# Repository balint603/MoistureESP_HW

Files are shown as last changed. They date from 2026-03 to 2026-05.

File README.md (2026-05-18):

# Hardware for MoistureESP project.
## Description
This project aims to use the ESP32 in low power modes, discover its capabilites for low power application. Also, this sensor project would be useful for home gardens not to forget watering.
This is not a complete product, it can be considered as a devboard.

*Software component not published yet.*
*3D case not published yet.*
## Software
See repository: [https://github.com/balint603/moist](https://github.com/balint603/moist)
## Components
- *This PCB project*
- ESP32-WROOM-32
- SOILCAP-V20 humidity measure
- DS18B20 sensor
- *SW not ready yet*
- *BMS configuration not ready yet*
## Features
- BMS cell protection.
- Overvoltage protection for battery input.
- Charger with USB (not tested).
- Wi-Fi MQTT data transmission.
- Selectable sensor measure interval.
## Interfaces
- Wi-Fi communication aimed to be used for sharing sensor data.
- Analog input for moisture sensor board (SOILCAP-V20).
- 1-Wire interface for DS18B20 temperature sensor.
- BMS I2C lines.
- UART for ESP programming and debug with RTS, DTS secondary programming feature.
- *Optional I2C for display.*
## Power
- Sized for 18650 battery cell, BMS tested with NCR18650B.
- Optinally Li-ion charger can be connected.
- Built-in USB charger was not tested.
### BMS configuration
1. Disable 2 cell: Settings->DA configuration->CC0 bit needs to be set to zero.
    - Otherwise it causes CUV and discharge FET will not turn on.
## Prerequisites
- KiCAD v10.0.0 

## Release
- V1.0: USB charger not tested.

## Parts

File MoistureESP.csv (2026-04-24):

Reference | Qty | Value | DNP | Exclude from BOM | Exclude from Board | Footprint | Datasheet | Tolerance
Batt1 | 1 | NCR18650B |  |  |  | custom:NCR18650
C1,C2,C3,C4,C6,C7,C8,C9,C14,C15,C16,C27 | 12 | 100nF |  |  |  | Capacitor_SMD:C_0603_1608Metric_Pad1.08x0.95mm_HandSolder
C5,C12,C13 | 3 | 2.2uF |  |  |  | Capacitor_SMD:C_0603_1608Metric_Pad1.08x0.95mm_HandSolder
C10,C11 | 2 | 1uF |  |  |  | Capacitor_SMD:C_0603_1608Metric_Pad1.08x0.95mm_HandSolder
C17 | 1 | 22uF |  |  |  | Capacitor_SMD:C_0603_1608Metric_Pad1.08x0.95mm_HandSolder
C18,C20,C21 | 3 | 2.2uF | DNP |  |  | Capacitor_SMD:C_0603_1608Metric_Pad1.08x0.95mm_HandSolder
C19 | 1 | 100nF | DNP |  |  | Capacitor_SMD:C_0603_1608Metric_Pad1.08x0.95mm_HandSolder
C22,C23,C24,C25 | 4 | 10uF | DNP |  |  | Capacitor_SMD:C_0603_1608Metric_Pad1.08x0.95mm_HandSolder
C26 | 1 | 22uF | DNP |  |  | Capacitor_SMD:C_0603_1608Metric_Pad1.08x0.95mm_HandSolder
D1,D2 | 2 | ESD5Zxx |  |  |  | Diode_SMD:D_SOD-523 | https://www.onsemi.com/pdf/datasheet/esd5z2.5t1-d.pdf
D3 | 1 | BZT52H-AD3V3-QX | DNP |  |  | Diode_SMD:D_SOD-123F | https://diotec.com/tl_files/diotec/files/pdf/datasheets/bzt52b2v4.pdf
D4,D5 | 2 | LED | DNP |  |  | LED_SMD:LED_0603_1608Metric
D6,D7 | 2 | BZT52H-AD3V3-QX |  |  |  | Diode_SMD:D_SOD-123F | https://diotec.com/tl_files/diotec/files/pdf/datasheets/bzt52b2v4.pdf
D8 | 1 | BZT52H-B5V1 |  |  |  | Diode_SMD:D_SOD-123F | https://diotec.com/tl_files/diotec/files/pdf/datasheets/bzt52b2v4.pdf
F1 | 1 | 2.5A |  |  |  | Resistor_SMD:R_0603_1608Metric_Pad0.98x0.95mm_HandSolder
F2 | 1 | 500mA |  |  |  | Resistor_SMD:R_1206_3216Metric_Pad1.30x1.75mm_HandSolder
J1 | 1 | Conn_01x02_Pin |  |  |  | Connector_PinHeader_2.54mm:PinHeader_1x02_P2.54mm_Vertical
J2 | 1 | Conn_MoisturePCB |  |  |  | custom:sensorwirepads3x1
J3 | 1 | Conn_DS18B20 |  |  |  | custom:sensorwirepads3x1
J4 | 1 | Conn_01x06_Pin |  |  |  | Connector_PinHeader_2.54mm:PinHeader_1x06_P2.54mm_Vertical
J5 | 1 | Conn_01x03_Pin |  |  |  | Connector_PinHeader_2.54mm:PinHeader_1x03_P2.54mm_Vertical
J6 | 1 | Conn_01x04_Pin | DNP |  |  | Connector_PinHeader_2.54mm:PinHeader_1x04_P2.54mm_Vertical
J7 | 1 | USB4110-GF-A | DNP |  |  | custom:USB4110-GF-A_GCT | USB4110-GF-A
JP1,JP2 | 2 | Jumper_2_Bridged |  |  |  | Connector_PinHeader_2.54mm:PinHeader_1x02_P2.54mm_Vertical
L1 | 1 | HTEK25201T-R47MSR | DNP |  |  | Inductor_SMD:L_1008_2520Metric_Pad1.43x2.20mm_HandSolder
Q1,Q2 | 2 | SSM6K513NU-LF |  |  |  | custom:TRANS_SSM6K513NU-LF
Q3 | 1 | 2N7002W |  |  |  | custom:SOT65P220X100-3N
Q4,Q5 | 2 | RUM002N05T2L |  |  |  | Package_TO_SOT_SMD:SOT-723
Q6,Q7 | 2 | BC817W |  |  |  | Package_TO_SOT_SMD:SOT-323_SC-70 | https://www.onsemi.com/pub/Collateral/BC818-D.pdf
Q8,Q10 | 2 | SI7137DP-T1-GE3 |  |  |  | custom:MOSFET_7DP-T1-GE3_VIS | https://www.vishay.com/doc?69063
Q9 | 1 | BC856BLT1G0SCT-ND |  |  |  | Package_TO_SOT_SMD:SOT-23 | https://www.onsemi.com/pub/Collateral/BC860-D.pdf
R1,R3,R4,R10,R11,R13,R25 | 7 | 100R |  |  |  | Resistor_SMD:R_0603_1608Metric_Pad0.98x0.95mm_HandSolder
R2 | 1 | 2mR |  |  |  | Resistor_SMD:R_1206_3216Metric_Pad1.30x1.75mm_HandSolder |  | 1%
R5,R8 | 2 | 10M |  |  |  | Resistor_SMD:R_0603_1608Metric_Pad0.98x0.95mm_HandSolder
R6,R7 | 2 | 5K1 |  |  |  | Resistor_SMD:R_0603_1608Metric_Pad0.98x0.95mm_HandSolder
R9,R14,R15,R16,R23,R24,R26,R27,R28,R29,R30,R31,R39,R40,R41,R42,R43 | 17 | 10K |  |  |  | Resistor_SMD:R_0603_1608Metric_Pad0.98x0.95mm_HandSolder
R12 | 1 | 5R1 |  |  |  | Resistor_SMD:R_0603_1608Metric_Pad0.98x0.95mm_HandSolder
R17,R19 | 2 | 1.5M |  |  |  | Resistor_SMD:R_0603_1608Metric_Pad0.98x0.95mm_HandSolder |  | 1%
R18,R20 | 2 | 1.2M |  |  |  | Resistor_SMD:R_0603_1608Metric_Pad0.98x0.95mm_HandSolder |  | 1%
R21 | 1 | 5.1K | DNP |  |  | Resistor_SMD:R_0603_1608Metric_Pad0.98x0.95mm_HandSolder
R22 | 1 | 8.1K | DNP |  |  | Resistor_SMD:R_0603_1608Metric_Pad0.98x0.95mm_HandSolder
R32,R33 | 2 | 470R | DNP |  |  | Resistor_SMD:R_0603_1608Metric_Pad0.98x0.95mm_HandSolder
R34 | 1 | 10K | DNP |  |  | Resistor_SMD:R_0603_1608Metric_Pad0.98x0.95mm_HandSolder
R35 | 1 | 11K | DNP |  |  | Resistor_SMD:R_0603_1608Metric_Pad0.98x0.95mm_HandSolder
R36 | 1 | 4.7K |  |  |  | Resistor_SMD:R_0603_1608Metric_Pad0.98x0.95mm_HandSolder
R37 | 1 | 0R |  |  |  | Resistor_SMD:R_0603_1608Metric_Pad0.98x0.95mm_HandSolder
R38 | 1 | 15K |  |  |  | Resistor_SMD:R_0603_1608Metric_Pad0.98x0.95mm_HandSolder
SW1 | 1 | 147873-1 |  |  |  | custom:SW_147873-1
TH1 | 1 | NTCG103JH103JT1 |  |  |  | Resistor_SMD:R_0402_1005Metric_Pad0.72x0.64mm_HandSolder
U1 | 1 | BQ28Z620DRZR |  |  |  | custom:VSON12_DRZ_TEX-L
U2,U3 | 2 | TPS7A2601DRVR |  |  |  | custom:DRV0006A
U4 | 1 | ESP32-WROOM-32 |  |  |  | RF_Module:ESP32-WROOM-32 | https://www.espressif.com/sites/default/files/documentation/esp32-wroom-32_datasheet_en.pdf
U5 | 1 | MAX77757JEFG420+ | DNP |  |  | 21-100385B_90-100128_MXM | MAX77757HEFG360+

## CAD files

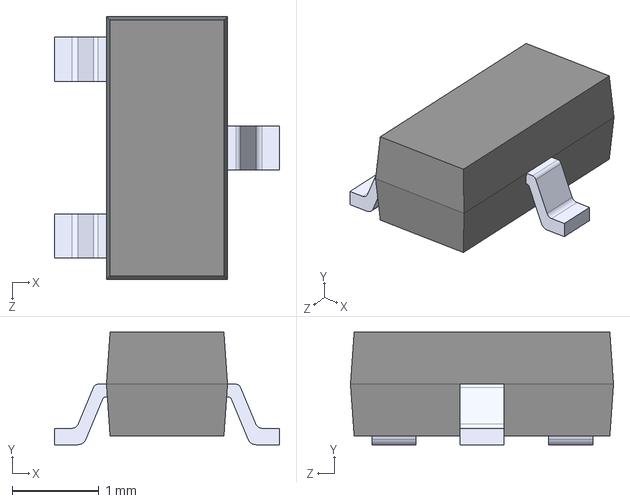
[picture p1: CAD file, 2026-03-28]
footprints/2N7002W/2N7002W.step
2.60 x 1.30 x 3.04 mm

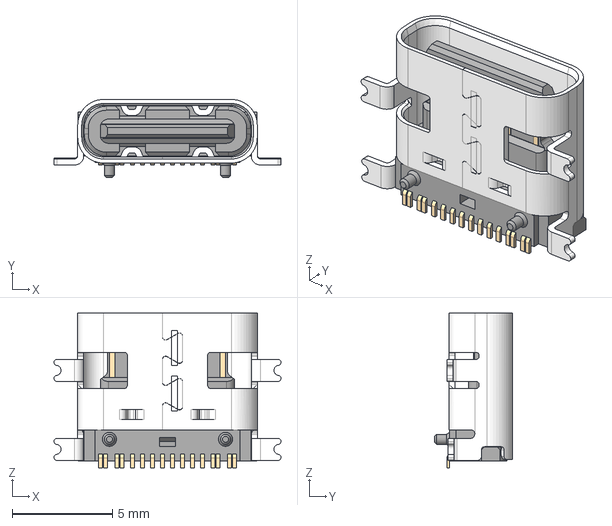
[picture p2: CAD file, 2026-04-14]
footprints/USB4110-GF-A.stp
11.3 x 3.89 x 7.70 mm

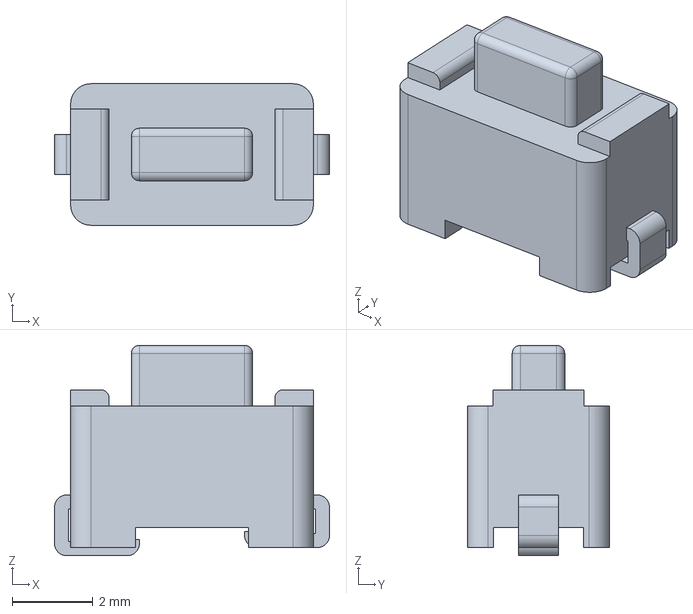
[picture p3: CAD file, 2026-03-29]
footprints/147873-1/147873-1.step
6.80 x 3.50 x 5.20 mm

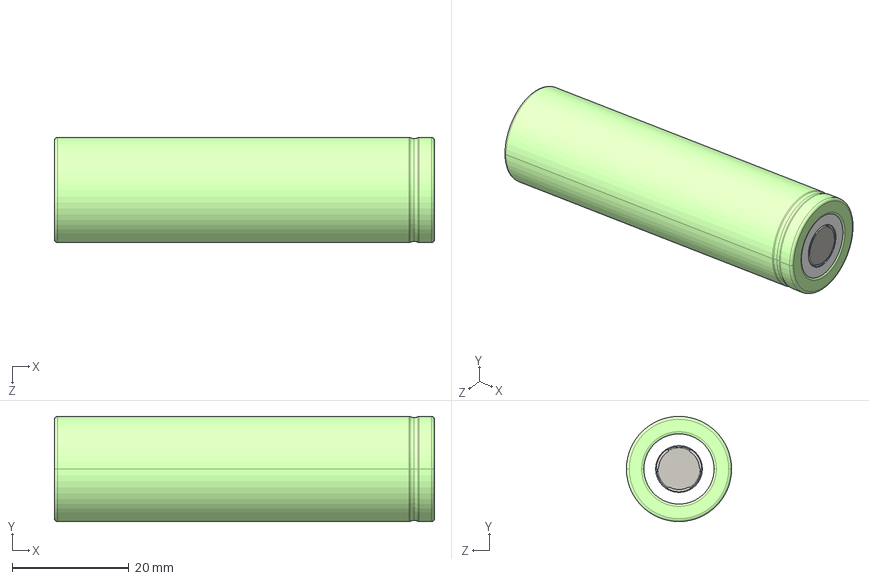
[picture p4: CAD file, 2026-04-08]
footprints/18650 battery.STEP
65.0 x 18.0 x 18.0 mm
battery terminal -
battery washer
battery case
battery terminal +

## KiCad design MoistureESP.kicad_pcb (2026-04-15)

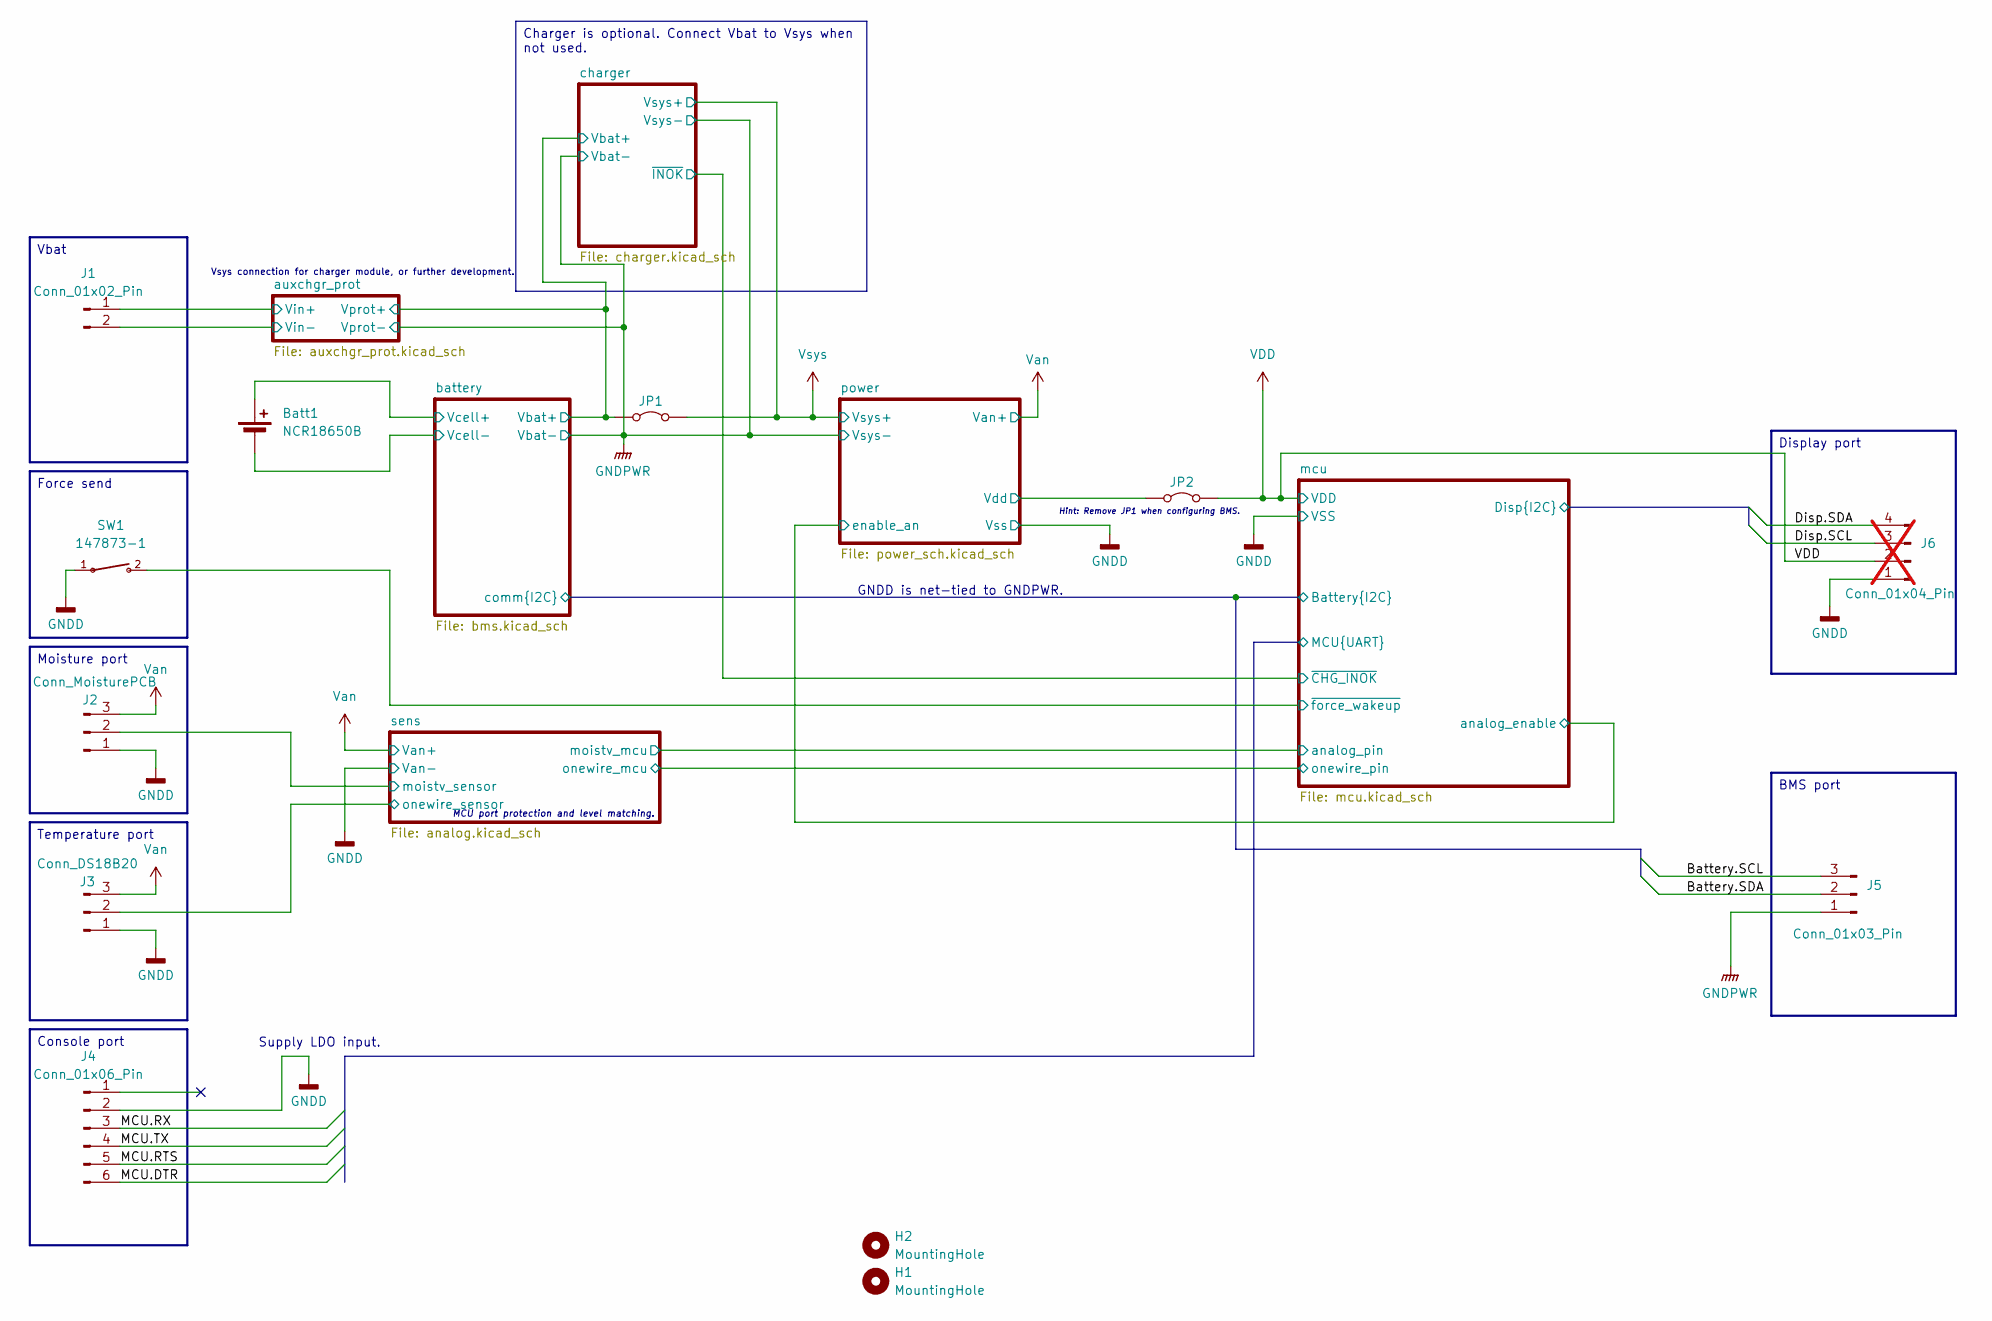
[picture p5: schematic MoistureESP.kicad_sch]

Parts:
Batt1: NCR18650B; NCR18650
H1, H2: MountingHole; MountingHole_2.7mm_M2.5_DIN965
J1: Conn_01x02_Pin; PinHeader_1x02_P2.54mm_Vertical
J2: Conn_MoisturePCB; sensorwirepads3x1
J3: Conn_DS18B20; sensorwirepads3x1
J4: Conn_01x06_Pin; PinHeader_1x06_P2.54mm_Vertical
J5: Conn_01x03_Pin; PinHeader_1x03_P2.54mm_Vertical
J6: Conn_01x04_Pin; PinHeader_1x04_P2.54mm_Vertical; not fitted
JP1, JP2: Jumper_2_Bridged; PinHeader_1x02_P2.54mm_Vertical
SW1: 147873-1; SW_147873-1; PARTREV K3

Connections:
/auxchgr_prot/Vin+: J1.1; also elsewhere on the board
/battery/Vcell+: Batt1.1 (+); also elsewhere on the board
/battery/comm.SCL: J5.3; also elsewhere on the board
/battery/comm.SDA: J5.2; also elsewhere on the board
/charger/VBat: JP1.1 (A); also elsewhere on the board
/mcu/Disp.SCL: J6.3; also elsewhere on the board
/mcu/Disp.SDA: J6.4; also elsewhere on the board
/mcu/MCU.DTR: J4.6; also elsewhere on the board
/mcu/MCU.RTS: J4.5; also elsewhere on the board
/mcu/MCU.RX: J4.3; also elsewhere on the board
/mcu/MCU.TX: J4.4; also elsewhere on the board
/mcu/onewire_pin: J3.2; also elsewhere on the board
/mcu/~force_wakeup: SW1.2; also elsewhere on the board
/power/Vdd: JP2.1 (A); also elsewhere on the board
/sens/moistv_sensor: J2.2; also elsewhere on the board
CGND: Batt1.2 (-); also elsewhere on the board
GNDD: J2.1, J3.1, J4.2, J6.1, SW1.1; also elsewhere on the board
GNDPWR: J1.2, J5.1; also elsewhere on the board
VDD: J6.2, JP2.2 (B); also elsewhere on the board
Van: J2.3, J3.3; also elsewhere on the board
Vsys: JP1.2 (B); also elsewhere on the board

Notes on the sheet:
Vsys connection for charger module, or further development.
MCU port protection and level matching.
Supply LDO input.
GNDD is net-tied to GNDPWR.
Hint: Remove JP1 when configuring BMS.
Vbat
Temperature port
Force send
Console port
Charger is optional. Connect Vbat to Vsys when not used.
Display port
BMS port
Moisture port

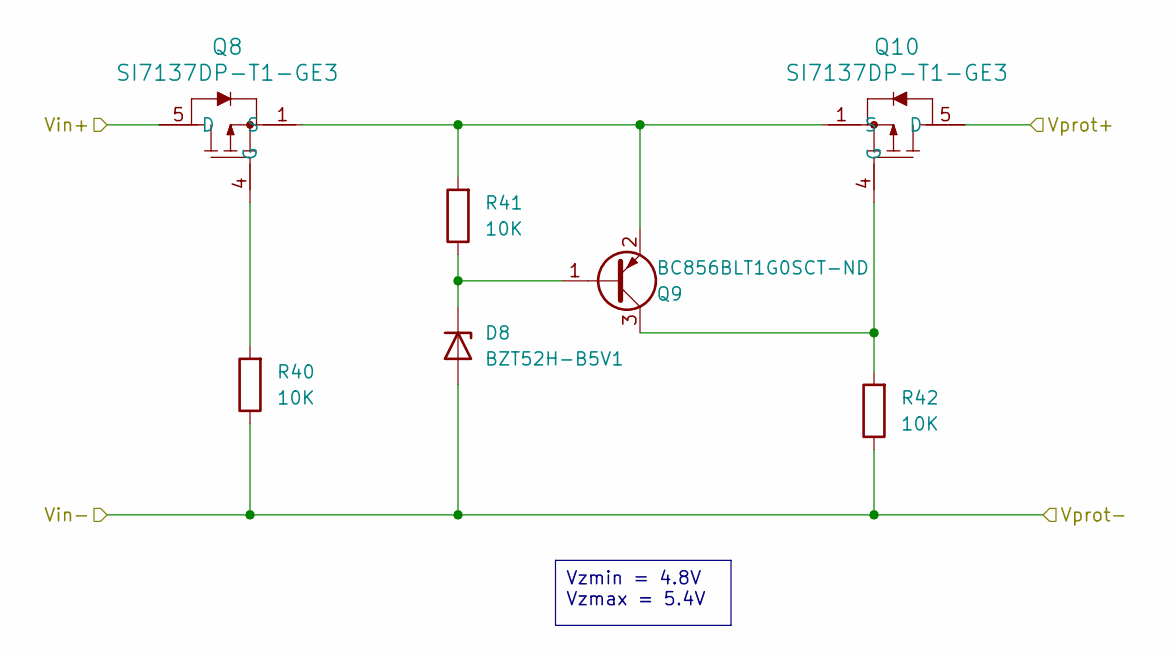
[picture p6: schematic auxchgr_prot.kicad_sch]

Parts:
D8: BZT52H-B5V1; D_SOD-123F
Q8, Q10: SI7137DP-T1-GE3; MOSFET_7DP-T1-GE3_VIS
Q9: BC856BLT1G0SCT-ND; SOT-23
R40, R41, R42: 10K; R_0603_1608Metric_Pad0.98x0.95mm_HandSolder

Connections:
/auxchgr_prot/Vin+: Q8.5 (D); also elsewhere on the board
/charger/VBat: Q10.5 (D); also elsewhere on the board
GNDPWR: D8.2 (A), R40.1, R42.1; also elsewhere on the board
unnamed: D8.1 (K), Q9.1 (B), R41.1
unnamed: Q8.4 (G), R40.2
unnamed: Q8.1 (S), Q8.2 (S), Q8.3 (S), Q9.2 (E), Q10.1 (S), Q10.2 (S), Q10.3 (S), R41.2
unnamed: Q9.3 (C), Q10.4 (G), R42.2

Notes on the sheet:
Vzmin = 4.8V Vzmax = 5.4V

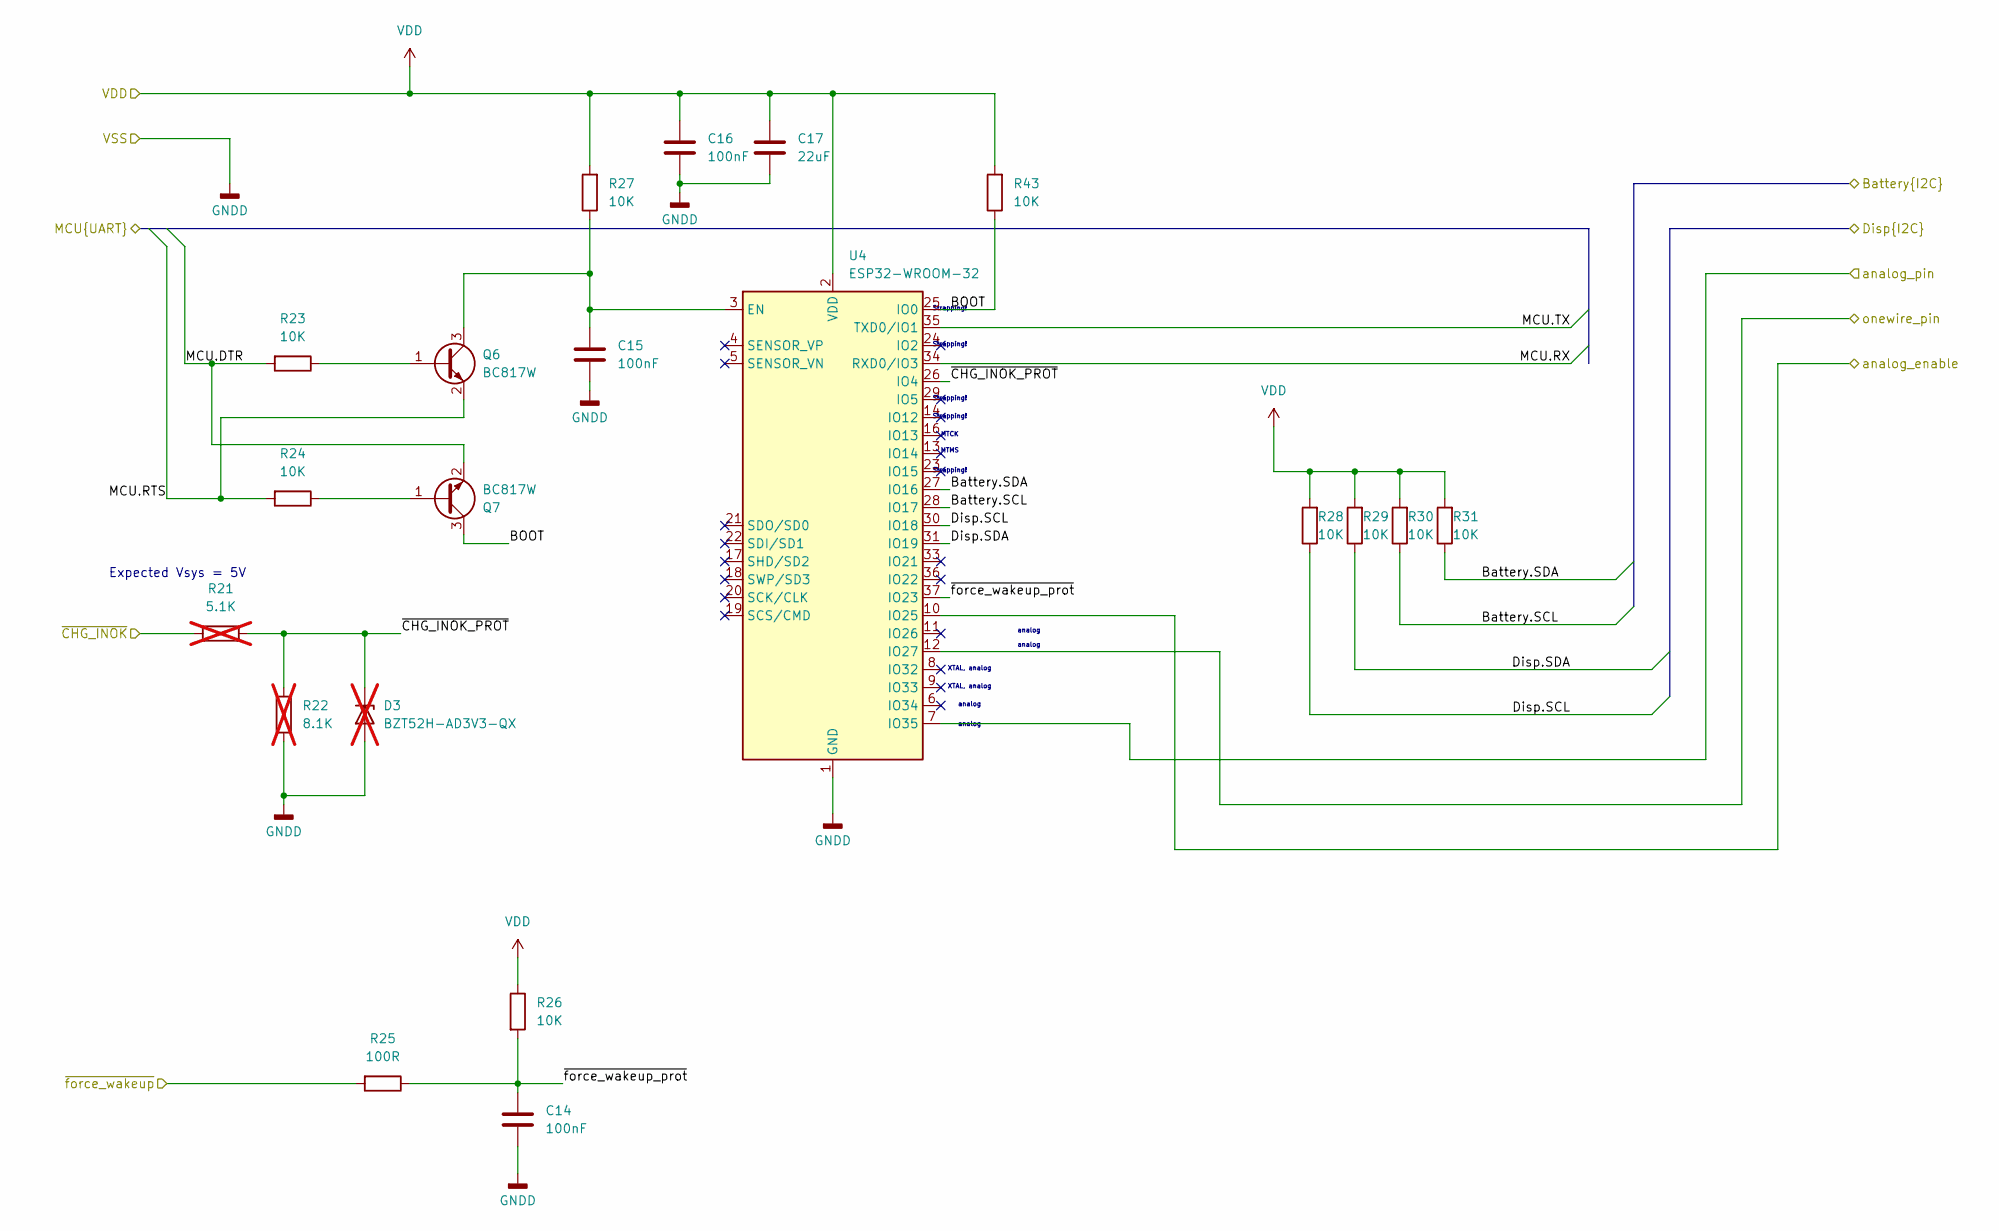
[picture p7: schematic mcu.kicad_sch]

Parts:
C14, C15, C16: 100nF; C_0603_1608Metric_Pad1.08x0.95mm_HandSolder; Voltage 25V
C17: 22uF; C_0603_1608Metric_Pad1.08x0.95mm_HandSolder; Voltage 10V
D3: BZT52H-AD3V3-QX; D_SOD-123F; not fitted
Q6, Q7: BC817W; SOT-323_SC-70
R21: 5.1K; R_0603_1608Metric_Pad0.98x0.95mm_HandSolder; not fitted
R22: 8.1K; R_0603_1608Metric_Pad0.98x0.95mm_HandSolder; not fitted
R23, R24, R26, R27, R28, R29, R30, R31, R43: 10K; R_0603_1608Metric_Pad0.98x0.95mm_HandSolder
R25: 100R; R_0603_1608Metric_Pad0.98x0.95mm_HandSolder
U4: ESP32-WROOM-32

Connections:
/battery/comm.SCL: R30.1, U4.28 (IO17); also elsewhere on the board
/battery/comm.SDA: R31.1, U4.27 (IO16); also elsewhere on the board
/charger/~INOK: R21.2; also elsewhere on the board
/mcu/BOOT: Q7.3 (C), R43.1, U4.25 (IO0)
/mcu/Disp.SCL: R28.1, U4.30 (IO18); also elsewhere on the board
/mcu/Disp.SDA: R29.1, U4.31 (IO19); also elsewhere on the board
/mcu/MCU.DTR: Q7.2 (E), R23.2; also elsewhere on the board
/mcu/MCU.RTS: Q6.2 (E), R24.2; also elsewhere on the board
/mcu/MCU.RX: U4.34 (RXD0/IO3); also elsewhere on the board
/mcu/MCU.TX: U4.35 (TXD0/IO1); also elsewhere on the board
/mcu/analog_enable: U4.10 (IO25); also elsewhere on the board
/mcu/analog_pin: U4.7 (IO35); also elsewhere on the board
/mcu/onewire_pin: U4.12 (IO27); also elsewhere on the board
/mcu/~CHG_INOK_PROT: D3.1 (K), R21.1, R22.1, U4.26 (IO4)
/mcu/~force_wakeup_prot: C14.1, R25.1, R26.2, U4.37 (IO23)
/mcu/~force_wakeup: R25.2; also elsewhere on the board
GNDD: C14.2, C15.2, C16.2, C17.2, D3.2 (A), R22.2, U4.1 (GND), U4.15 (GND), U4.38 (GND), U4.39 (GND); also elsewhere on the board
unnamed: Q6.1 (B), R23.1
unnamed: C15.1, Q6.3 (C), R27.1, U4.3 (EN)
unnamed: Q7.1 (B), R24.1
VDD: C16.1, C17.1, R26.1, R27.2, R28.2, R29.2, R30.2, R31.2, R43.2, U4.2 (VDD); also elsewhere on the board

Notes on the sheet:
analog
XTAL, analog
Strapping!
MTCK
Expected Vsys = 5V
MTMS

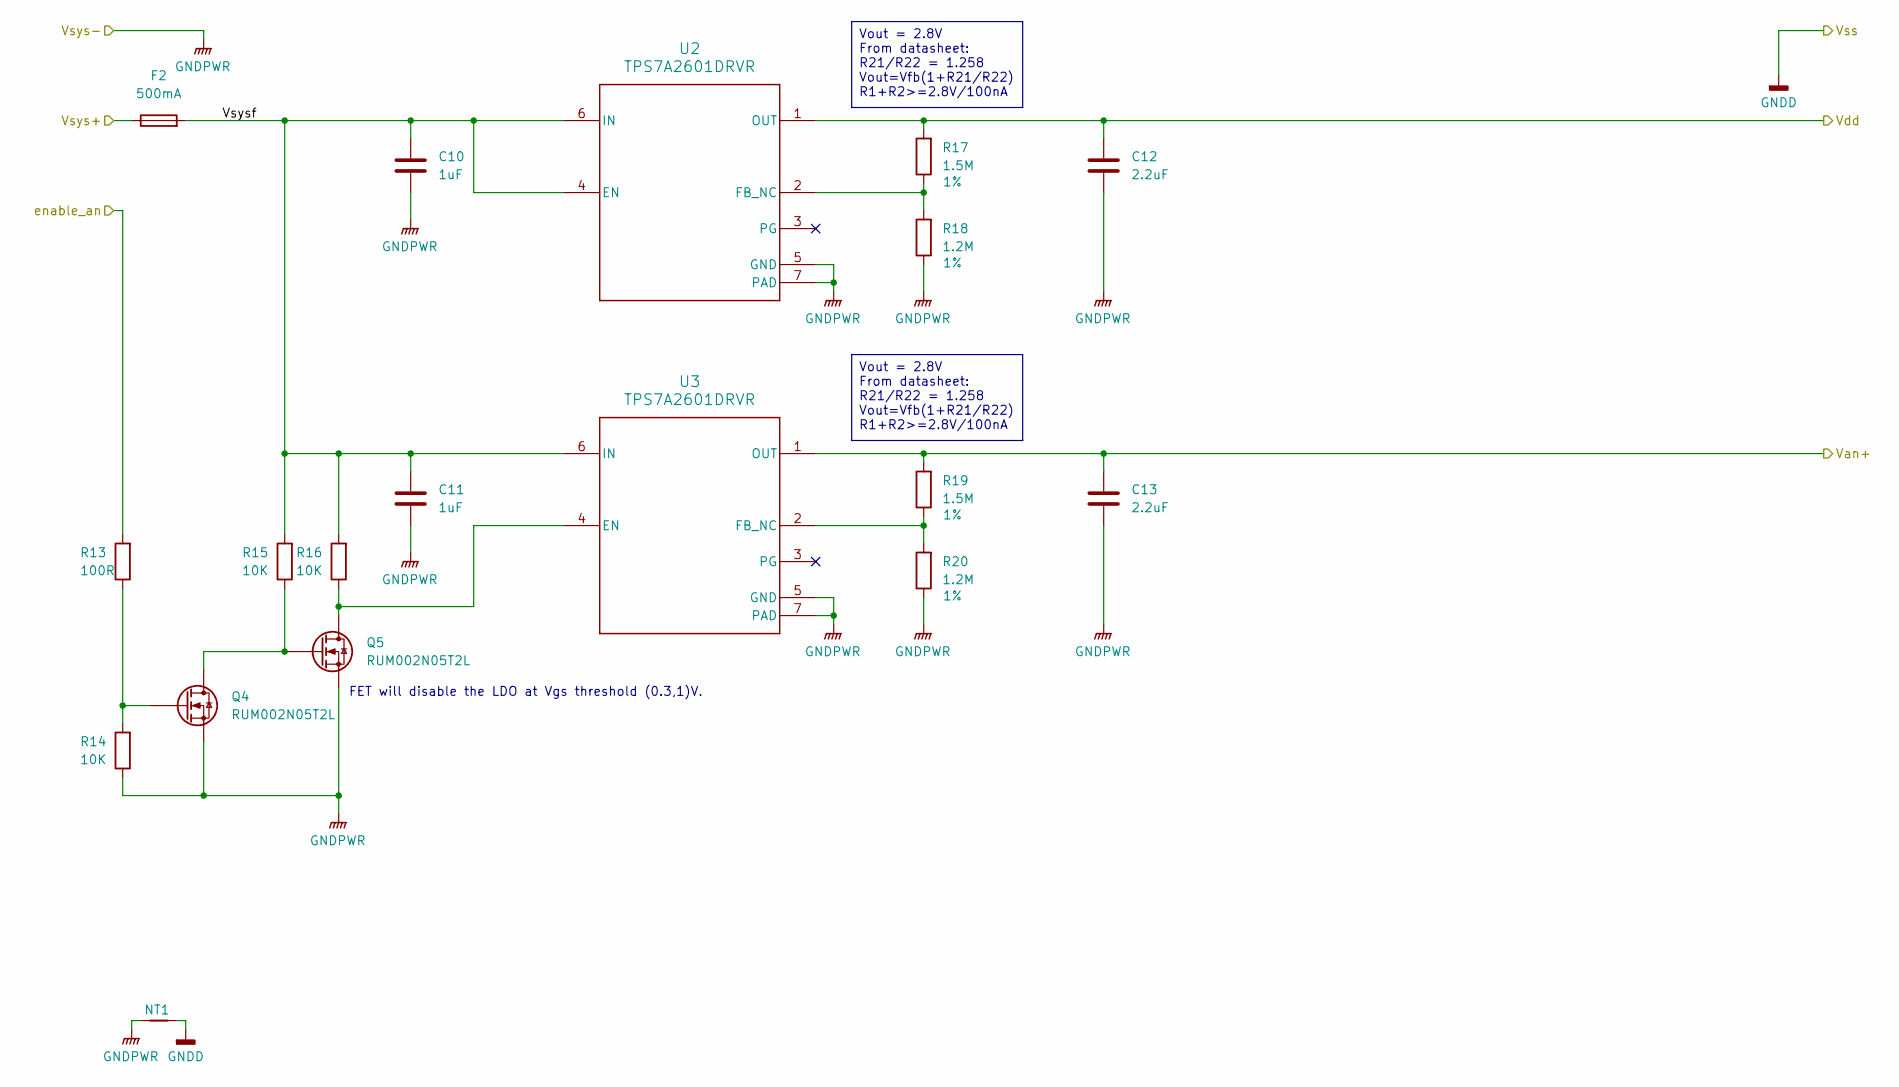
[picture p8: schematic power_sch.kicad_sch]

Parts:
C10, C11: 1uF; C_0603_1608Metric_Pad1.08x0.95mm_HandSolder
C12, C13: 2.2uF; C_0603_1608Metric_Pad1.08x0.95mm_HandSolder
F2: 500mA; R_1206_3216Metric_Pad1.30x1.75mm_HandSolder
NT1: NetTie_2; NetTie-2_SMD_Pad2.0mm
Q4, Q5: RUM002N05T2L; SOT-723
R13: 100R; R_0603_1608Metric_Pad0.98x0.95mm_HandSolder
R14, R15, R16: 10K; R_0603_1608Metric_Pad0.98x0.95mm_HandSolder
R17, R19: 1.5M; R_0603_1608Metric_Pad0.98x0.95mm_HandSolder; Tolerance 1%
R18, R20: 1.2M; R_0603_1608Metric_Pad0.98x0.95mm_HandSolder; Tolerance 1%
U2, U3: TPS7A2601DRVR; DRV0006A

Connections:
/mcu/analog_enable: R13.2; also elsewhere on the board
/power/Vdd: C12.2, R17.2, U2.1 (OUT); also elsewhere on the board
/power/Vsysf: C10.2, C11.2, F2.2, R15.2, R16.2, U2.4 (EN), U2.6 (IN), U3.6 (IN)
GNDD: NT1.2; also elsewhere on the board
GNDPWR: C10.1, C11.1, C12.1, C13.1, NT1.1, Q4.2 (S), Q5.2 (S), R14.1, R18.1, R20.1, U2.5 (GND), U2.7 (PAD), U3.5 (GND), U3.7 (PAD); also elsewhere on the board
unnamed: Q4.3 (D), Q5.1 (G), R15.1
unnamed: Q4.1 (G), R13.1, R14.2
unnamed: Q5.3 (D), R16.1, U3.4 (EN)
unnamed: R17.1, R18.2, U2.2 (FB_NC)
unnamed: R19.1, R20.2, U3.2 (FB_NC)
Van: C13.2, R19.2, U3.1 (OUT); also elsewhere on the board
Vsys: F2.1; also elsewhere on the board

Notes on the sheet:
FET will disable the LDO at Vgs threshold (0.3,1)V.
Vout = 2.8V From datasheet: R21/R22 = 1.258 Vout=Vfb(1+R21/R22) R1+R2>=2.8V/100nA

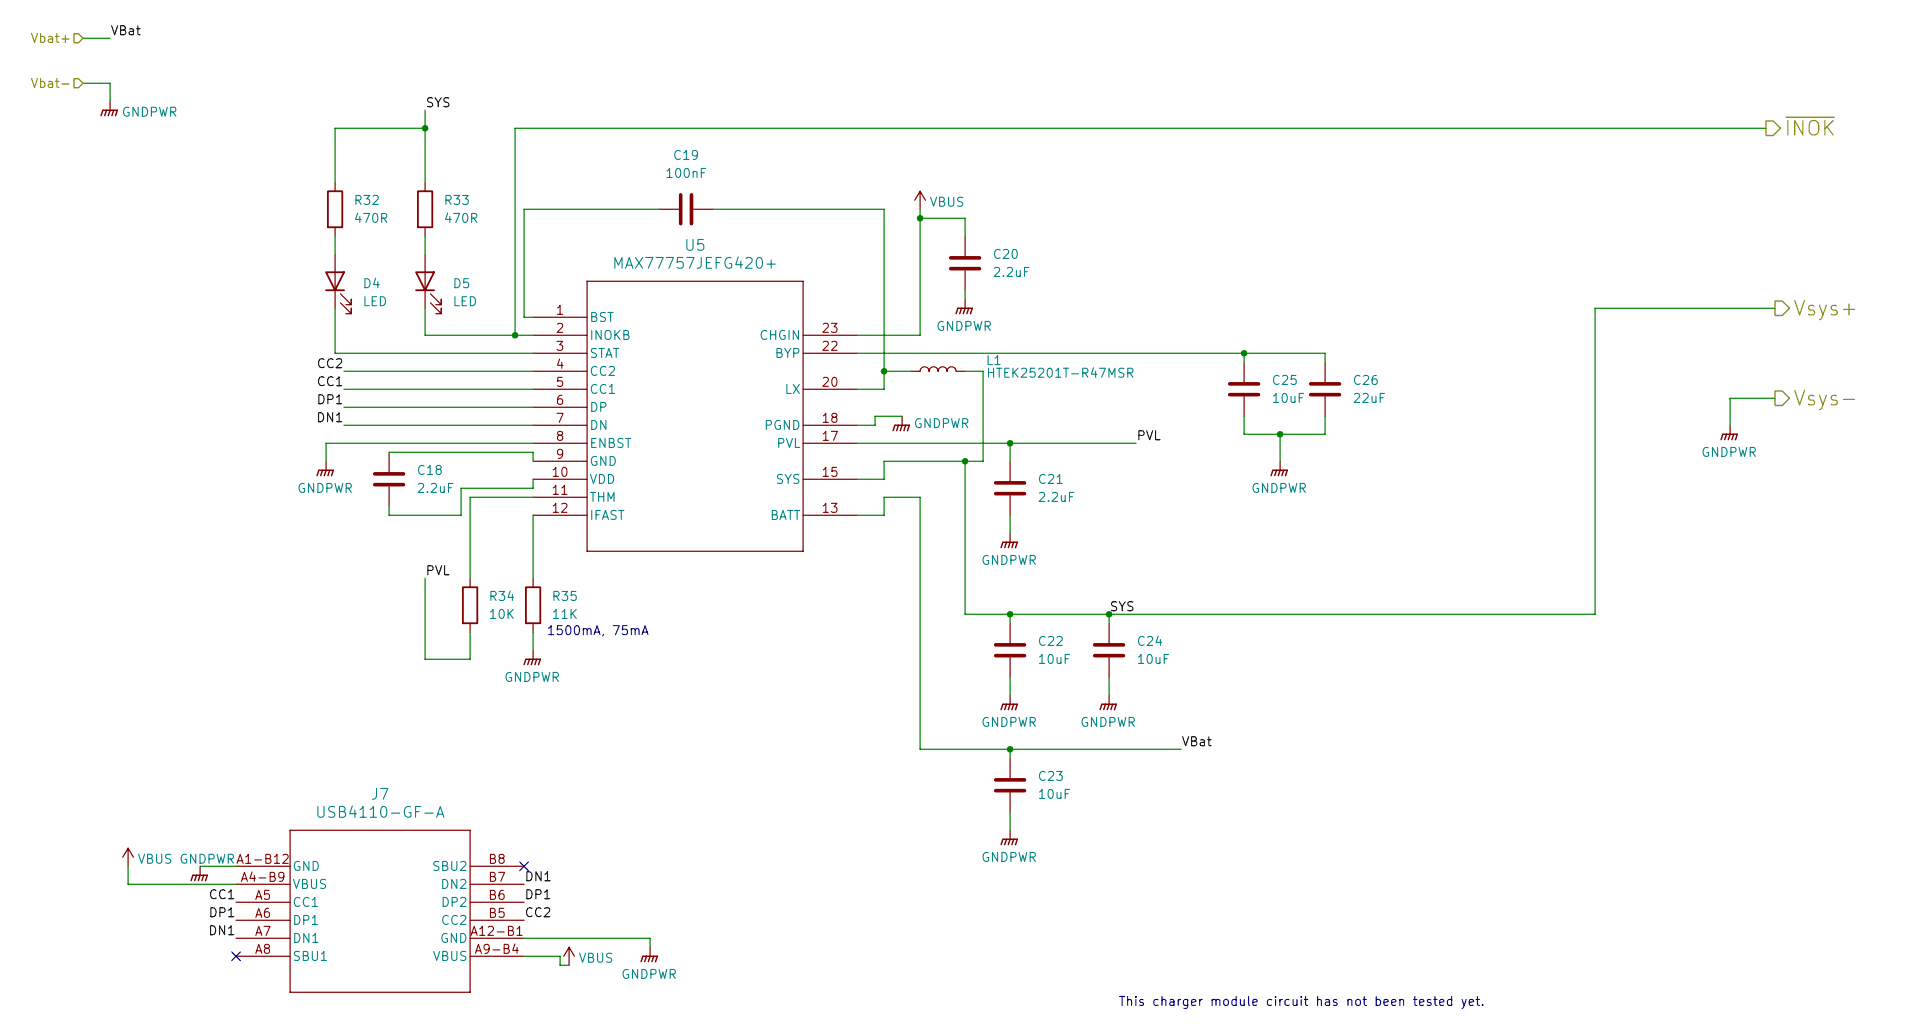
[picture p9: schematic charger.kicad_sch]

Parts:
C18, C20, C21: 2.2uF; C_0603_1608Metric_Pad1.08x0.95mm_HandSolder; Voltage 25V
C19: 100nF; C_0603_1608Metric_Pad1.08x0.95mm_HandSolder; Voltage 25V
C22, C23, C24, C25: 10uF; C_0603_1608Metric_Pad1.08x0.95mm_HandSolder; Voltage 25V
C26: 22uF; C_0603_1608Metric_Pad1.08x0.95mm_HandSolder; Voltage 25V
D4, D5: LED; LED_0603_1608Metric
J7: USB4110-GF-A; USB4110-GF-A_GCT
L1: HTEK25201T-R47MSR; L_1008_2520Metric_Pad1.43x2.20mm_HandSolder
R32, R33: 470R; R_0603_1608Metric_Pad0.98x0.95mm_HandSolder
R34: 10K; R_0603_1608Metric_Pad0.98x0.95mm_HandSolder
R35: 11K; R_0603_1608Metric_Pad0.98x0.95mm_HandSolder
U5: MAX77757JEFG420+; 21-100385B_90-100128_MXM

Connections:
/charger/CC1: J7.A5 (CC1), U5.5 (CC1)
/charger/CC2: J7.B5 (CC2), U5.4 (CC2)
/charger/DN1: J7.A7 (DN1), J7.B7 (DN2), U5.7 (DN)
/charger/DP1: J7.A6 (DP1), J7.B6 (DP2), U5.6 (DP)
/charger/PVL: C21.2, R34.2, U5.17 (PVL)
/charger/VBat: C23.2, U5.13 (BATT); also elsewhere on the board
/charger/~INOK: D5.1 (K), U5.2 (INOKB); also elsewhere on the board
GNDPWR: C20.1, C21.1, C22.1, C23.1, C24.1, C25.1, C26.1, J7.A1-B12 (GND), J7.A12-B1 (GND), R35.2, U5.8 (ENBST), U5.18 (PGND); also elsewhere on the board
unnamed: D4.2 (A), R32.2
unnamed: D4.1 (K), U5.3 (STAT)
unnamed: D5.2 (A), R33.2
unnamed: C19.2, U5.1 (BST)
unnamed: C25.2, C26.2, U5.22 (BYP)
unnamed: C18.2, U5.9 (GND)
unnamed: R35.1, U5.12 (IFAST)
unnamed: C19.1, L1.1, U5.20 (LX)
unnamed: R34.1, U5.11 (THM)
unnamed: C18.1, U5.10 (VDD)
VBUS: C20.2, J7.A4-B9 (VBUS), J7.A9-B4 (VBUS), U5.23 (CHGIN)
Vsys: C22.2, C24.2, L1.2, R32.1, R33.1, U5.15 (SYS); also elsewhere on the board

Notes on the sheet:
1500mA, 75mA
This charger module circuit has not been tested yet.

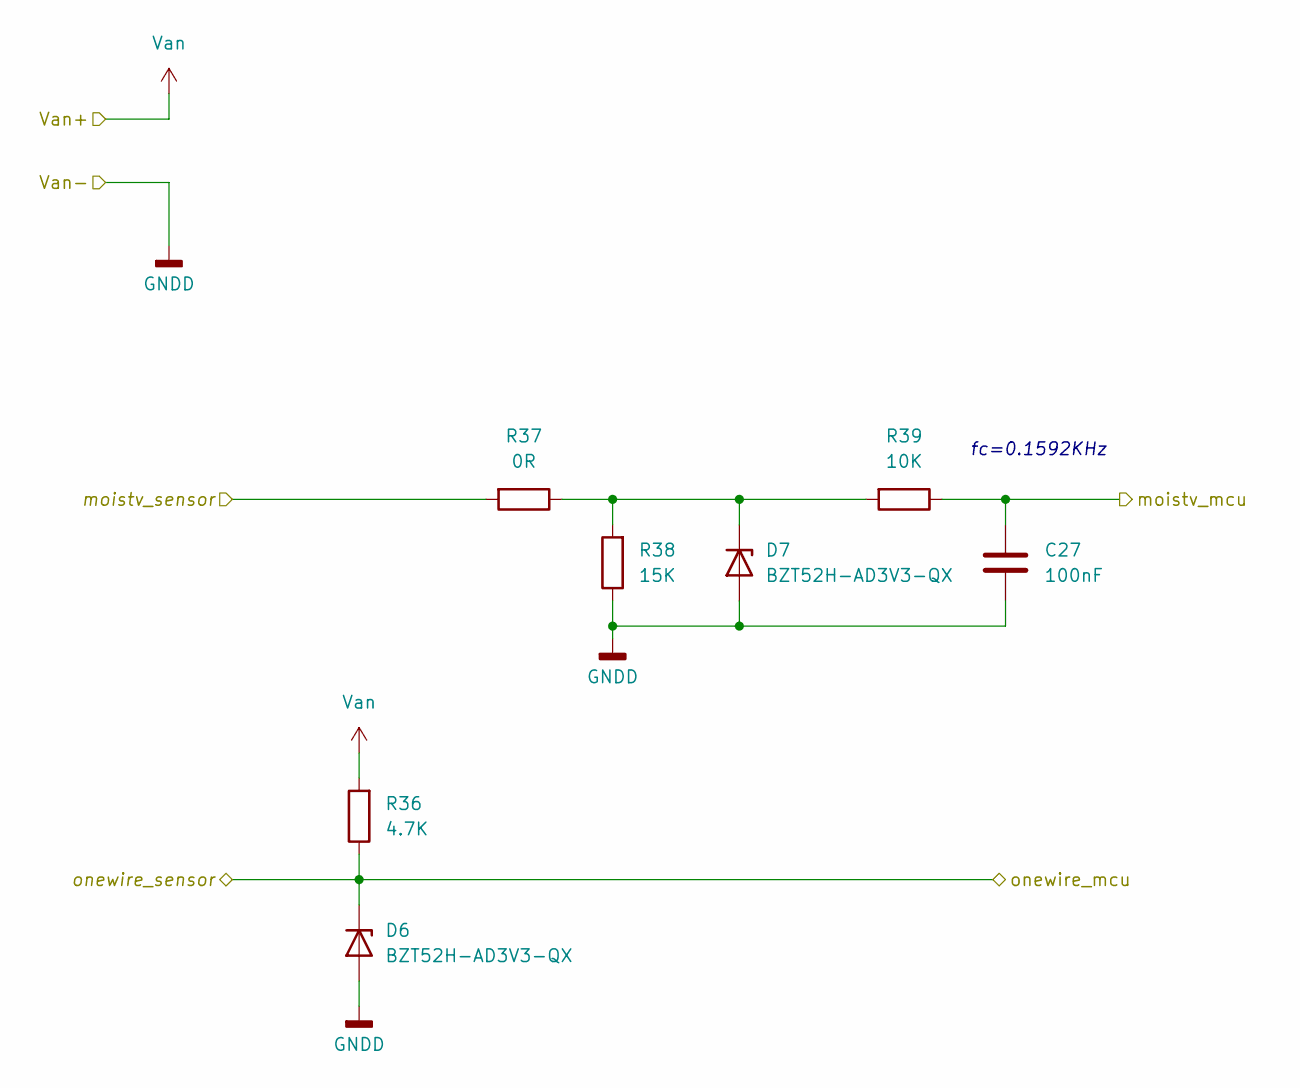
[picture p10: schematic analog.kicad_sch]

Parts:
C27: 100nF; C_0603_1608Metric_Pad1.08x0.95mm_HandSolder
D6, D7: BZT52H-AD3V3-QX; D_SOD-123F
R36: 4.7K; R_0603_1608Metric_Pad0.98x0.95mm_HandSolder
R37: 0R; R_0603_1608Metric_Pad0.98x0.95mm_HandSolder
R38: 15K; R_0603_1608Metric_Pad0.98x0.95mm_HandSolder
R39: 10K; R_0603_1608Metric_Pad0.98x0.95mm_HandSolder

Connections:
/mcu/analog_pin: C27.2, R39.1; also elsewhere on the board
/mcu/onewire_pin: D6.1 (K), R36.1; also elsewhere on the board
/sens/moistv_sensor: R37.2; also elsewhere on the board
GNDD: C27.1, D6.2 (A), D7.2 (A), R38.1; also elsewhere on the board
unnamed: D7.1 (K), R37.1, R38.2, R39.2
Van: R36.2; also elsewhere on the board

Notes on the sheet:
fc=0.1592KHz

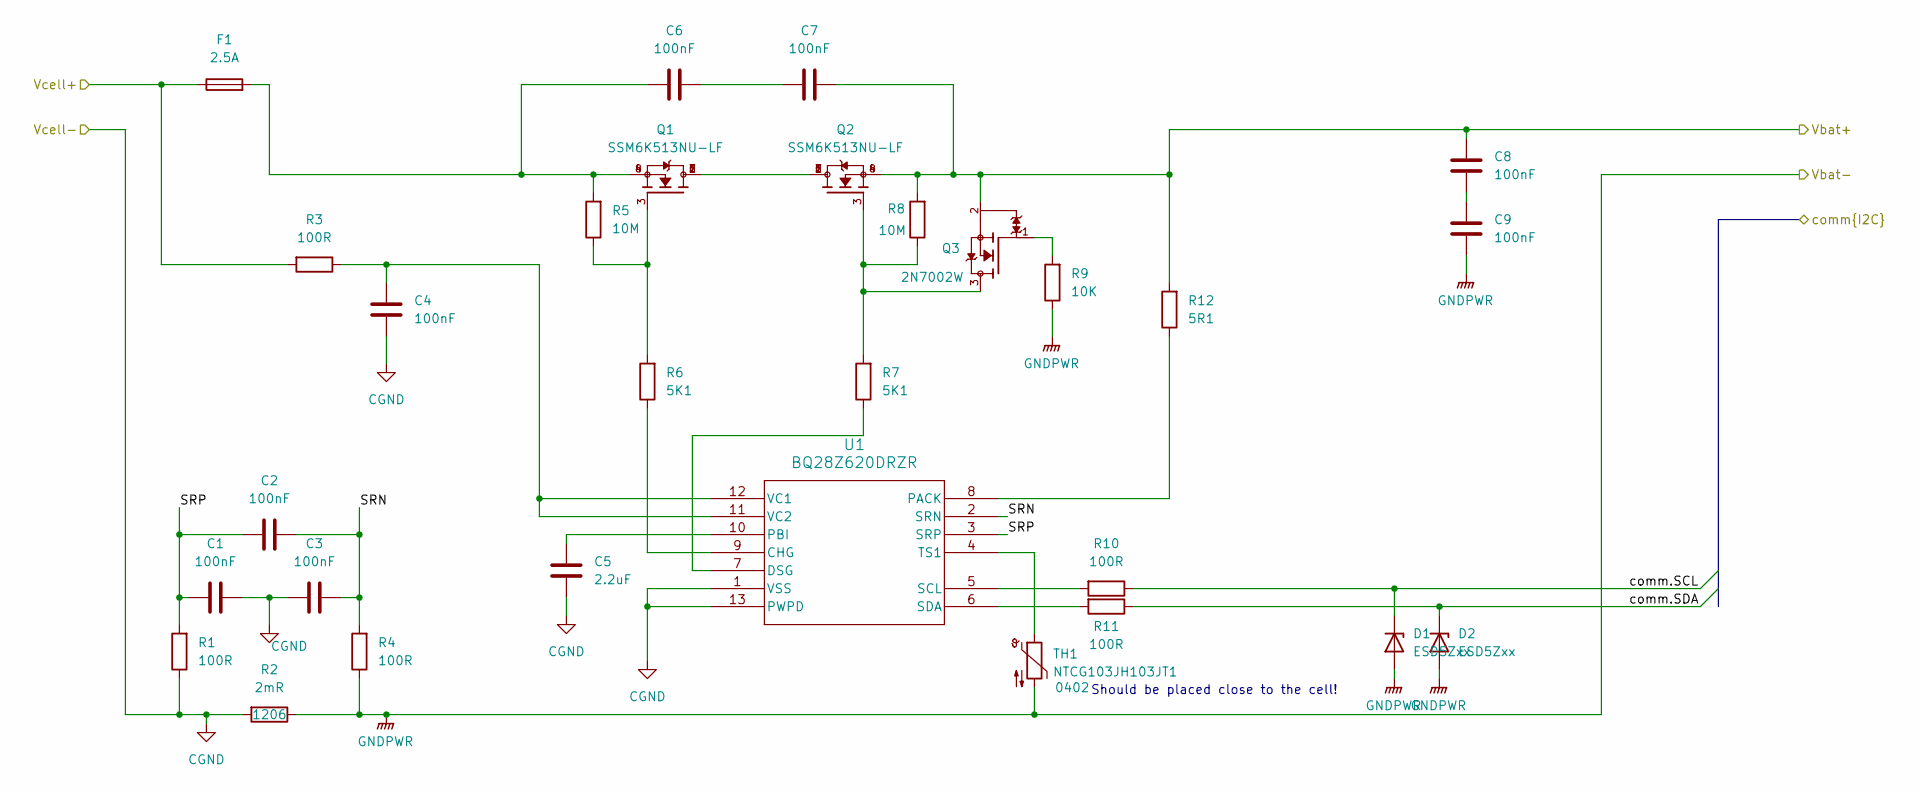
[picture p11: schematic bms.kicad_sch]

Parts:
C1, C2, C3, C4, C6, C7, C8, C9: 100nF; C_0603_1608Metric_Pad1.08x0.95mm_HandSolder
C5: 2.2uF; C_0603_1608Metric_Pad1.08x0.95mm_HandSolder
D1, D2: ESD5Zxx; D_SOD-523
F1: 2.5A; R_0603_1608Metric_Pad0.98x0.95mm_HandSolder
Q1, Q2: SSM6K513NU-LF; TRANS_SSM6K513NU-LF
Q3: 2N7002W; SOT65P220X100-3N
R1, R3, R4, R10, R11: 100R; R_0603_1608Metric_Pad0.98x0.95mm_HandSolder
R2: 2mR; R_1206_3216Metric_Pad1.30x1.75mm_HandSolder; Tolerance 1%
R5, R8: 10M; R_0603_1608Metric_Pad0.98x0.95mm_HandSolder
R6, R7: 5K1; R_0603_1608Metric_Pad0.98x0.95mm_HandSolder
R9: 10K; R_0603_1608Metric_Pad0.98x0.95mm_HandSolder
R12: 5R1; R_0603_1608Metric_Pad0.98x0.95mm_HandSolder
TH1: NTCG103JH103JT1; R_0402_1005Metric_Pad0.72x0.64mm_HandSolder
U1: BQ28Z620DRZR; VSON12_DRZ_TEX-L

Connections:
/battery/SRN: C2.2, C3.2, R4.2, U1.2 (SRN)
/battery/SRP: C1.1, C2.1, R1.2, U1.3 (SRP)
/battery/Vcell+: F1.1, R3.2; also elsewhere on the board
/battery/comm.SCL: D1.1 (K), R10.1; also elsewhere on the board
/battery/comm.SDA: D2.1 (K), R11.1; also elsewhere on the board
/charger/VBat: C7.2, C8.2, Q2.4, Q2.8, Q3.2, R8.2, R12.2; also elsewhere on the board
CGND: C1.2, C3.1, C4.1, C5.1, R1.1, R2.2, U1.1 (VSS), U1.13 (PWPD); also elsewhere on the board
GNDPWR: C9.1, D1.2 (A), D2.2 (A), R2.1, R4.1, R9.1, TH1.2; also elsewhere on the board
unnamed: C6.1, F1.2, Q1.4, Q1.8, R5.2
unnamed: C6.2, C7.1
unnamed: C8.1, C9.2
unnamed: Q1.1, Q1.2, Q1.5, Q1.6, Q1.7, Q2.1, Q2.2, Q2.5, Q2.6, Q2.7
unnamed: Q1.3, R5.1, R6.2
unnamed: Q2.3, Q3.3, R7.2, R8.1
unnamed: Q3.1, R9.2
unnamed: R6.1, U1.9 (CHG)
unnamed: R7.1, U1.7 (DSG)
unnamed: R12.1, U1.8 (PACK)
unnamed: C5.2, U1.10 (PBI)
unnamed: R10.2, U1.5 (SCL)
unnamed: R11.2, U1.6 (SDA)
unnamed: TH1.1, U1.4 (TS1)
unnamed: C4.2, R3.1, U1.11 (VC2), U1.12 (VC1)

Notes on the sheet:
Should be placed close to the cell!

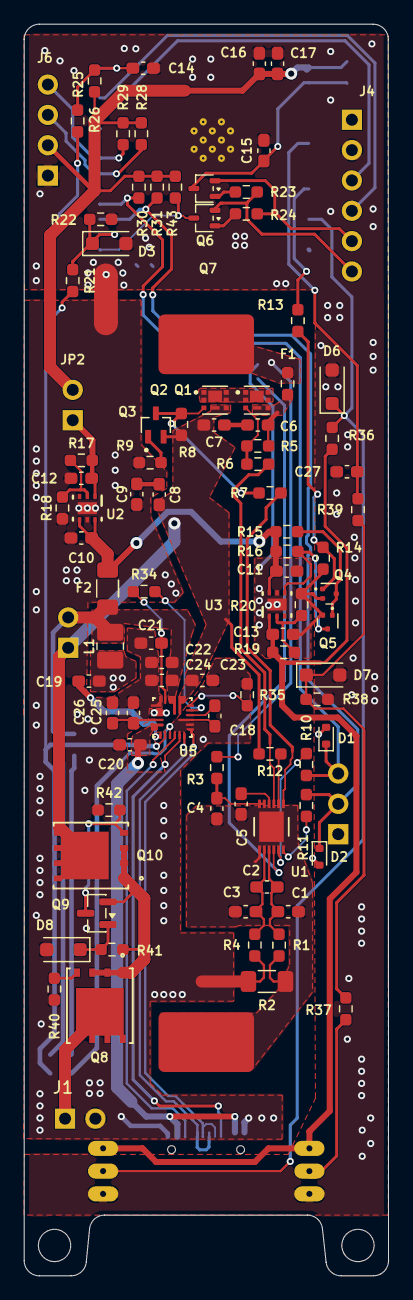
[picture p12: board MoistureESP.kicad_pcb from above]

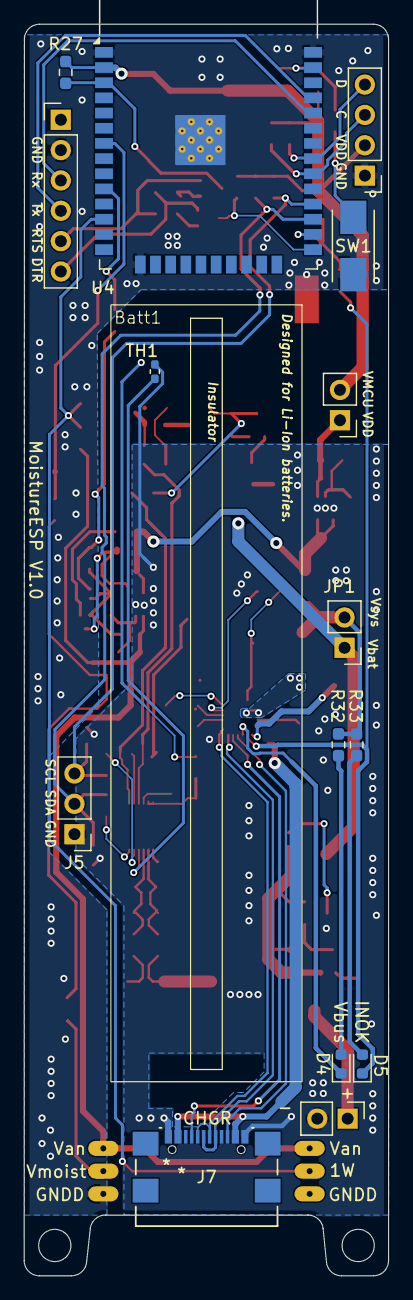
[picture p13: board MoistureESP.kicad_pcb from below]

Board: 2 copper layers, 30.5 x 104.8 mm, 111 parts (15 on the bottom side), 74 nets.

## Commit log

2026-03-28 Batter scematic done.
    [MoistureESP.kicad_sch, bms.kicad_sch]
2026-03-28 Draw power schematic.
    [MoistureESP.kicad_sch, bms.kicad_sch, mcu.kicad_sch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]
2026-03-28 Change BJT to FET in MCU. Add pinout.
    [MoistureESP.kicad_sch, mcu.kicad_sch, power_sch.kicad_sch]
2026-03-29 Add analog schematic and refine wiring on top.
    [147873-1.step, MoistureESP.kicad_sch, analog.kicad_sch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]
2026-03-29 Add charger, battery cell.
    [MoistureESP.kicad_sch, bms.kicad_sch, charger.kicad_sch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]
2026-03-30 Add console port.
    [MoistureESP.kicad_sch, charger.kicad_sch, power_sch.kicad_sch]
2026-03-30 Fix issues
    [MoistureESP.kicad_sch, bms.kicad_sch, charger.kicad_sch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]
2026-03-30 Fix issues from Issue#1
    [MoistureESP.kicad_pcb, MoistureESP.kicad_sch, bms.kicad_sch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]
2026-03-30 Refine wirings.
    [MoistureESP.kicad_sch]
2026-03-30 Add protected Vbat charger input.
    [MoistureESP.kicad_sch, analog.kicad_sch, auxchgr_prot.kicad_sch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]
2026-03-30 Fix wrong wiring, add pcb design.
    [MoistureESP.kicad_pcb, bms.kicad_sch, power_sch.kicad_sch]
2026-03-30 Add footprint to debug connector.
    [MoistureESP.kicad_pcb, MoistureESP.kicad_sch, bms.kicad_sch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]
2026-03-31 Start placement
    [MoistureESP.kicad_pcb, MoistureESP.kicad_sch]
2026-04-01 Add someplacement.
    [MoistureESP.kicad_pcb, mcu.kicad_sch]
2026-04-01 Change protection FETs and add resistor.
    [MoistureESP.kicad_pcb, auxchgr_prot.kicad_sch]
2026-04-01 Placement concept is finished.
    [MoistureESP.kicad_pcb, bms.kicad_sch, charger.kicad_sch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]
2026-04-02 Add wiring, change footprint to avoid fatal errors at pads.
    [MoistureESP.kicad_pcb, MoistureESP.kicad_sch, analog.kicad_sch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]
2026-04-04 Add VBAT polygon, add BQ control wiring.
    [MoistureESP.kicad_pcb, bms.kicad_sch]
2026-04-04 Fix BQ cell voltage wrong connection.
    [MoistureESP.kicad_pcb, bms.kicad_sch]
2026-04-04 Change USB charger position, redraw the zones.
    [MoistureESP.kicad_pcb, auxchgr_prot.kicad_sch]
2026-04-05 Change CGND connection to shunt resistor, change zone hierarchy.
    [MoistureESP.kicad_pcb]
2026-04-06 Refine VBAT zone and add wiring under MCU.
    [MoistureESP.kicad_pcb, MoistureESP.kicad_sch, power_sch.kicad_sch]
2026-04-07 Layout is finished with adding analog part, wiring the MCU ports and adding GNDD zones. Also add the nettie.
    [MoistureESP.kicad_pcb, bms.kicad_sch]
2026-04-07 Fixing DRCs. Modify polygons.
    [MoistureESP.kicad_pcb, power_sch.kicad_sch]
2026-04-08 Fix the actual DRC errors, add 3D model for cell. Fix also BQ28Z610 model.
    [18650 battery.STEP, MoistureESP.kicad_pcb]
2026-04-10 Fix ESP32 GPIO wiring, many bootstrap pins were used.
    [MoistureESP.kicad_pcb, MoistureESP.kicad_sch, mcu.kicad_sch]
2026-04-13 Editing layout, redrawing analog and RTS DTS signals. Placing the silk layer designators
    [MoistureESP.kicad_pcb, MoistureESP.kicad_sch, mcu.kicad_sch]
2026-04-13 Modify zones and adjustmenents in analog power.
    [MoistureESP.kicad_pcb]
2026-04-14 Edit silkscreen.
    [MoistureESP.kicad_pcb, USB4110-GF-A.stp]
2026-04-14 Editing silkscreen, move battery charge connector.
    [MoistureESP.kicad_pcb]
2026-04-15 Layout modification, refine connections and zone shapes.
    [MoistureESP.kicad_pcb]
2026-04-15 Finish refinements, prepare to release.
    [MoistureESP-B_Cu.gbr, MoistureESP-B_Mask.gbr, MoistureESP-B_Silkscreen.gbr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]
2026-04-15 Add drill files.
    [MoistureESP.kicad_pcb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]
2026-04-24 Export BOM, change page headers.
    [MoistureESP.csv, MoistureESP.kicad_sch, analog.kicad_sch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]

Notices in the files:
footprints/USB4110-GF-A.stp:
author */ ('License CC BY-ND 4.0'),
